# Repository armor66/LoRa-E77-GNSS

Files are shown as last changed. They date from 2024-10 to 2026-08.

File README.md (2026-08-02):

E77-128x160 contains st7735 1.8" and nv3023 2.08" lcd screen options, 
so you can uncomment #define ST7735 or #define NV3023 in the main.h respectively.

Also #define COMPASS_BLUE if use bno055 "blue" board with LDO
or comment it if use "pink" bno055 board without LDO.

PCB/Schematic_nv3023_PogoPins.pdf provides new pogo pins design.
PCB and CASE folders contain corresponding st7735 and nv3023 files.

E77-Beacon is for 52x36mm pcb design.
E77-tBeacon is new tiny 36x26mm pcb design with accelerometer ADXL345 on separate expansion board added via I2C pins PB6&PB7.
Which implements axis 'X' Double Tap and Activity detection.

For the very first time use CubeProgrammer with "Hardware reset" mode. Hold Reset button, press Connect, release Reset button. 
After that Browse for E77-128x160.bin or E77-tBeacon.bin and Start Programming.

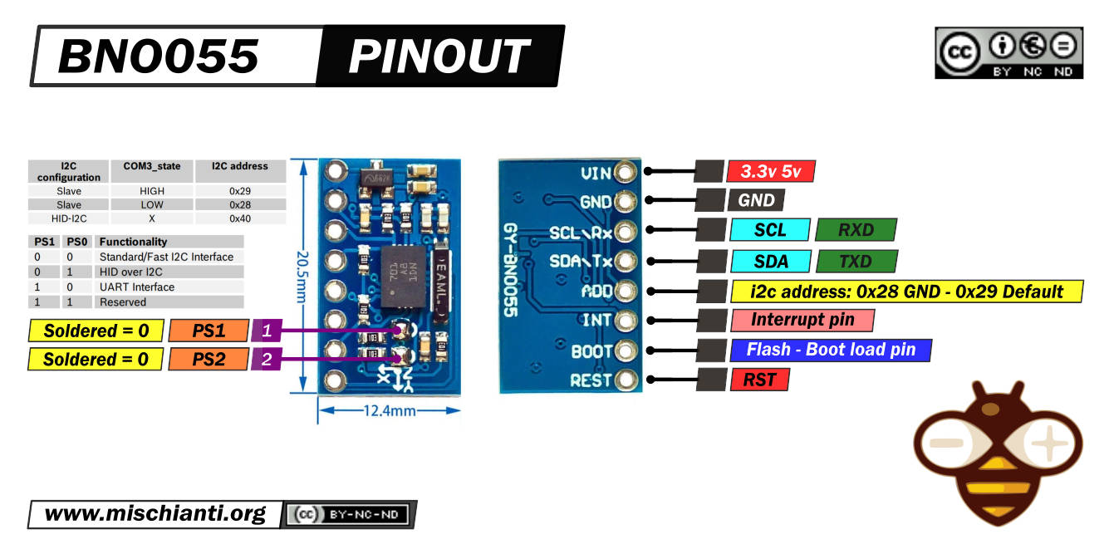
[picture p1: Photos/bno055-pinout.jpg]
module photo
As compass it is supposed to use external bno055 "blue" board with LDO.

Although it seemed more reliable "pink" board without LDO. However, it should be found another VCC connection point (after internal LDO). 
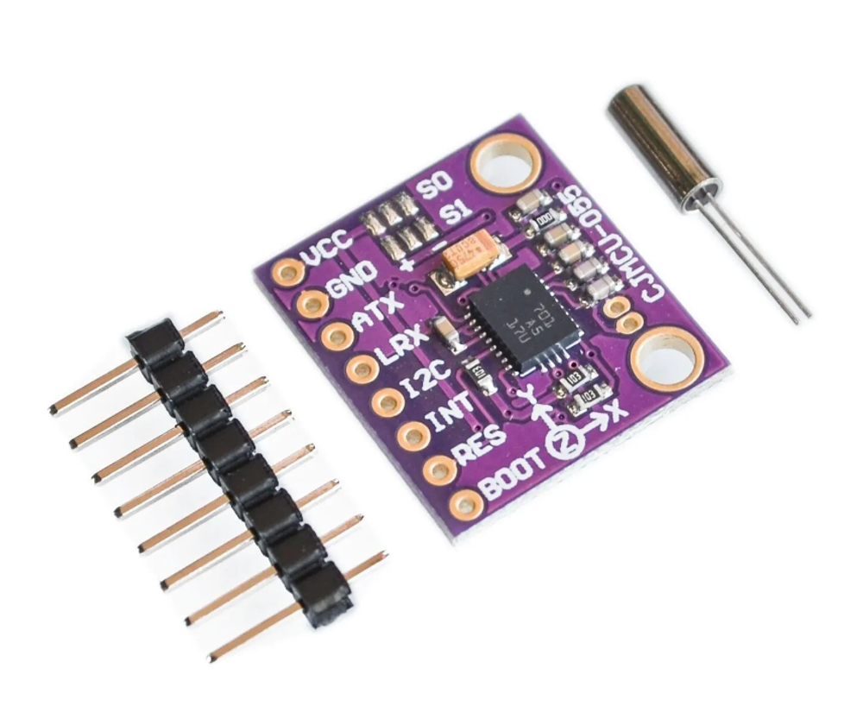
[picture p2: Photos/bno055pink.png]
module photo
S0 and S1 pads sould be soldered to GND

As GNSS module suggested to use 27x27mm QUESCAN with full set of connectors. Power Enable "EN" should not be connected 
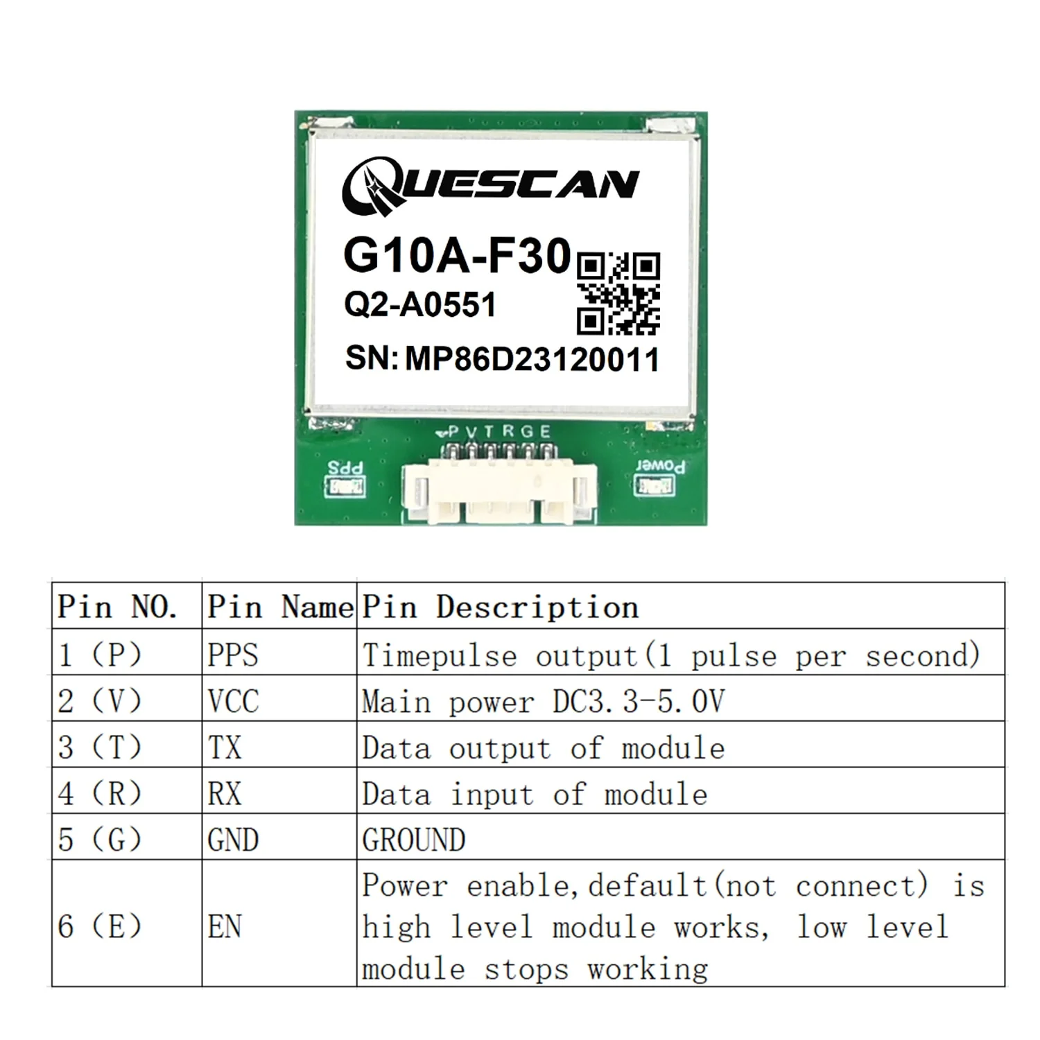
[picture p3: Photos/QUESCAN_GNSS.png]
module photo
(this MCU pin engaged for MUTE purpose)

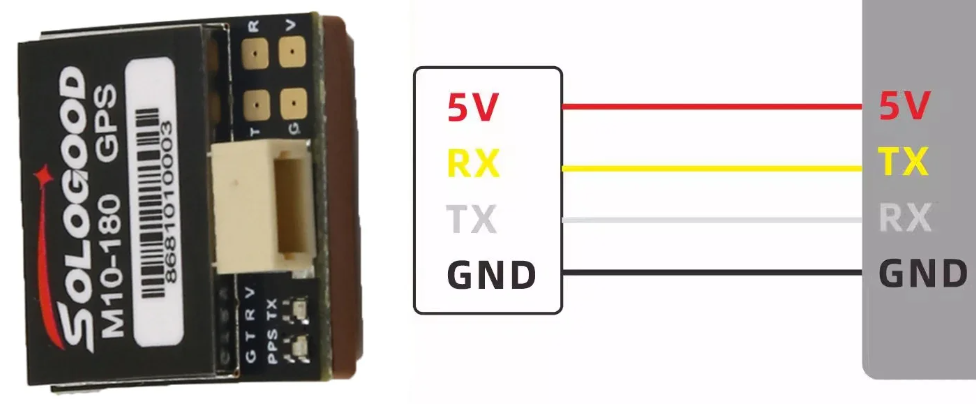
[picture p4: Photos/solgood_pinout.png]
module photo
As GNSS module for tBeacon proposing to use cheap 18x18mm SoloGood which demands soldering PPS after "PPS LED" being removed

or find a more suitable 18x18mm one that has PPS connector

3.7V Li-ion battery 103450 for handheld unit and 802535 or some similar for tBeacon.

##### How it looks inside
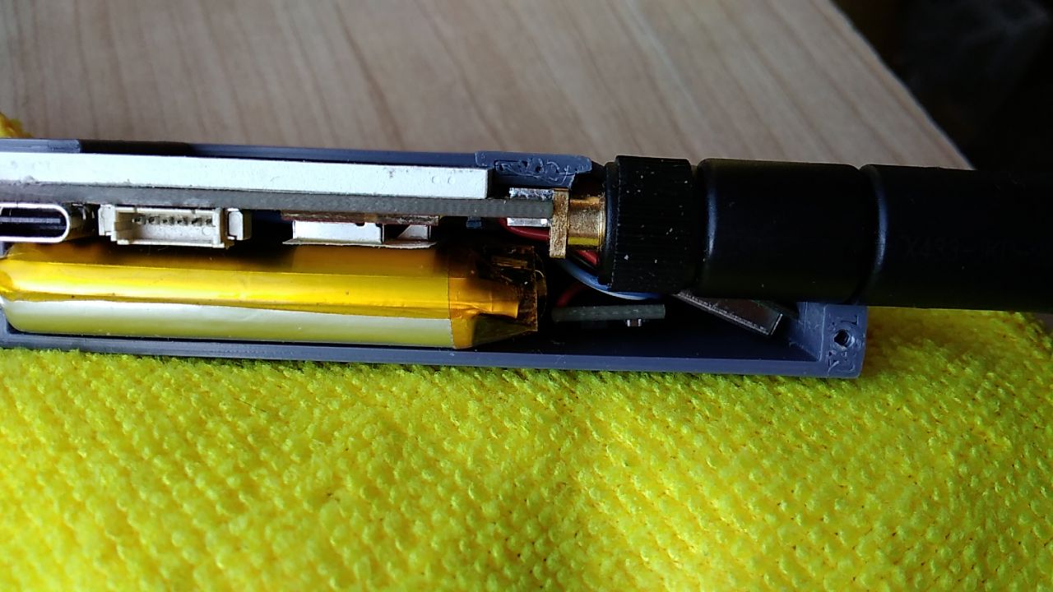
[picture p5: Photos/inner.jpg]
module photo

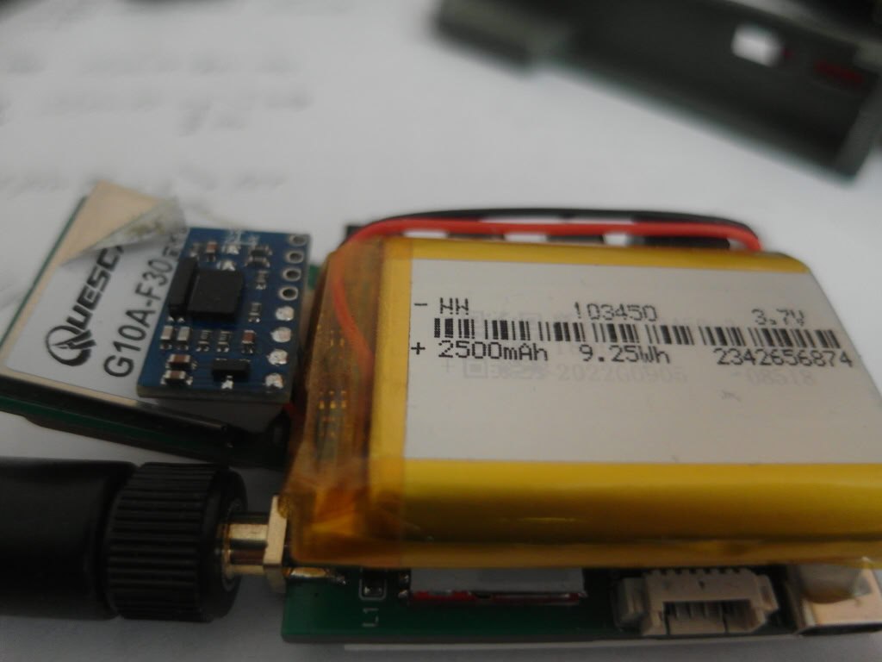
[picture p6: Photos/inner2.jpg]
module photo


##### Some photos
st7735 1.8" and nv3023 2.08" modules
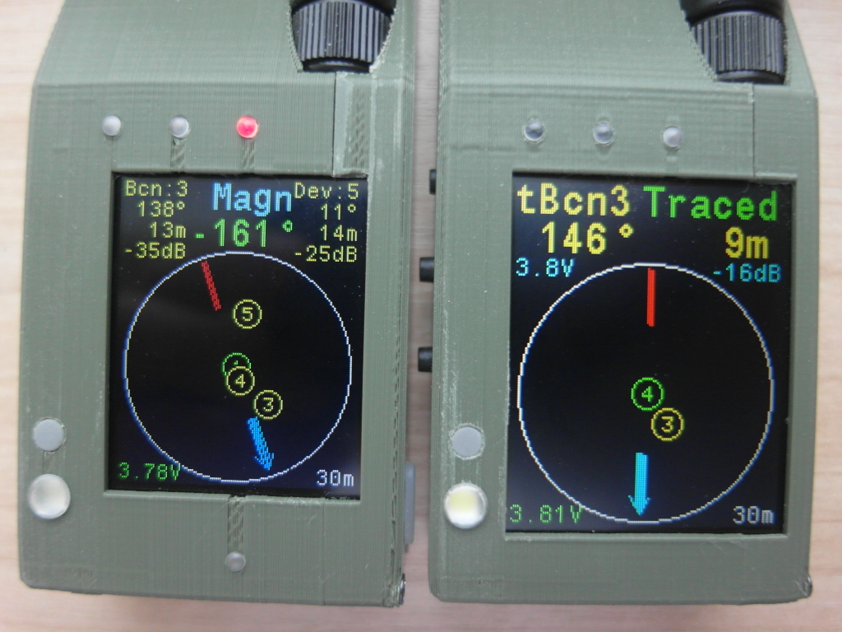
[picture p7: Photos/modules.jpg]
module photo


36x26mm PCB tBeacon
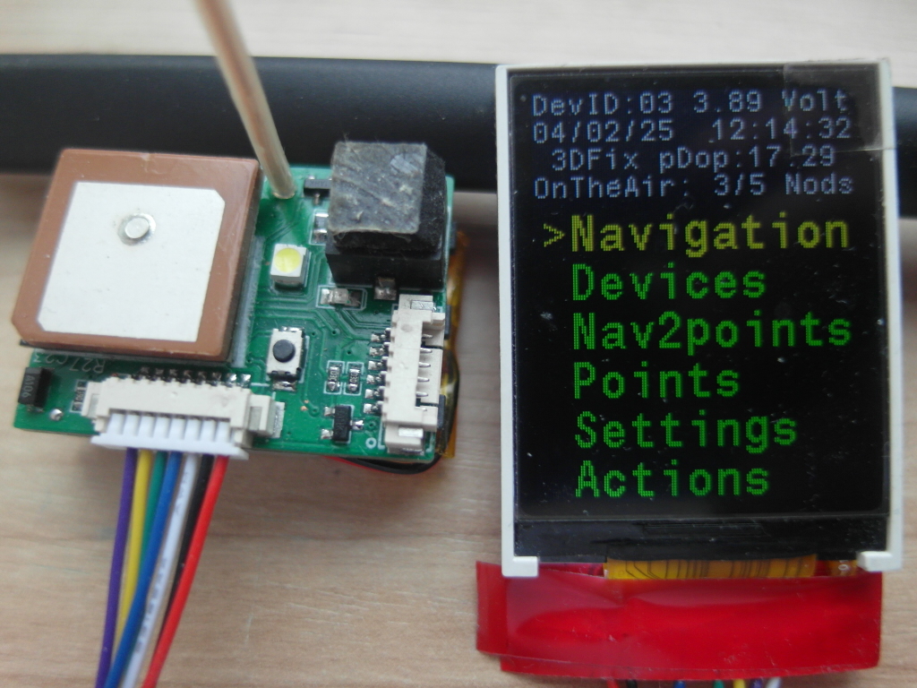
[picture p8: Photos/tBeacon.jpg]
beacon photo


52x36mm PCB Beacon
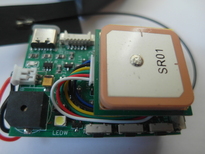
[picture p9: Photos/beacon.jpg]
beacon photo


Two tBeacons and st7735 PCB
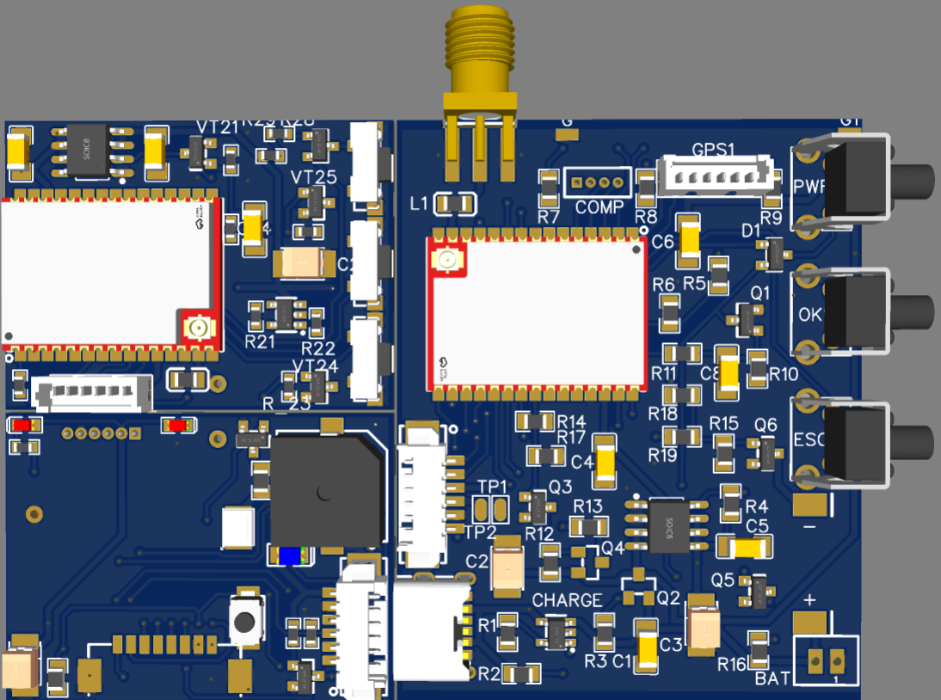
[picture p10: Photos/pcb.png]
beacon photo


HandHeld with PogoPins design
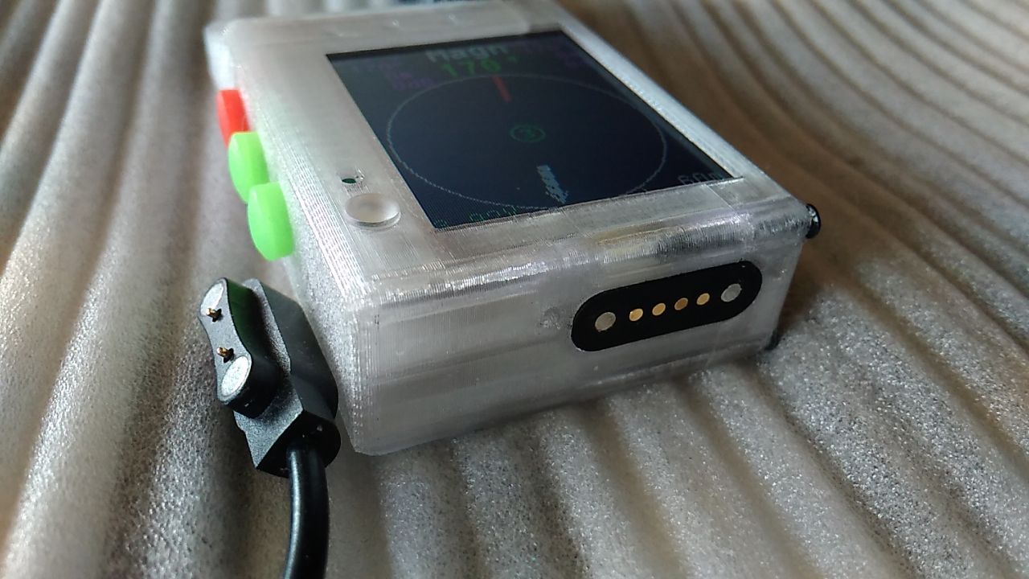
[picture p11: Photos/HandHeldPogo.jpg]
beacon photo


Beacon with PogoPins design
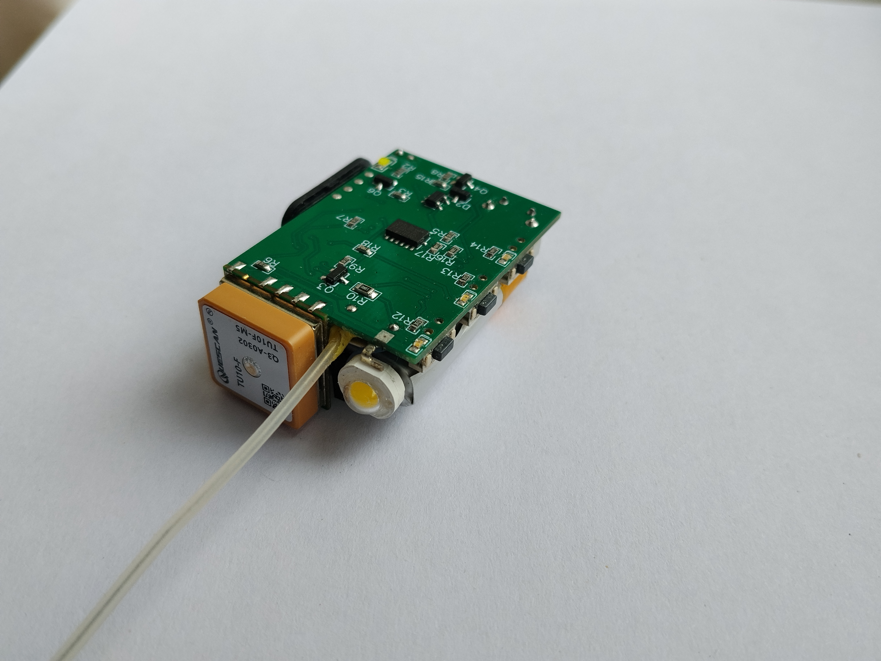
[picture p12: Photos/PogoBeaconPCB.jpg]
beacon photo

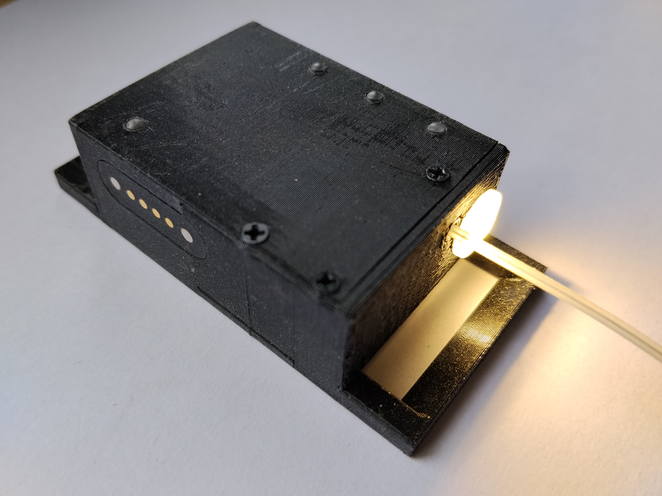
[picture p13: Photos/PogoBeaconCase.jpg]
beacon photo


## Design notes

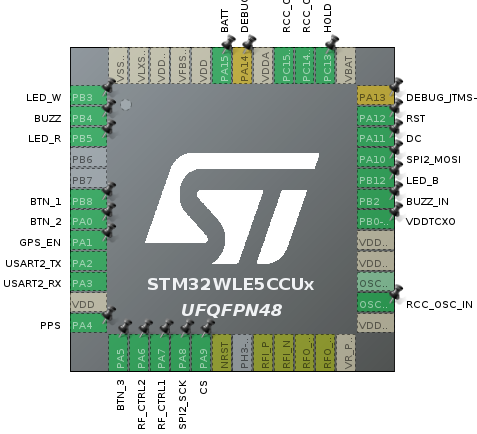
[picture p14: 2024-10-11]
Photos/PinoutBeacon.png

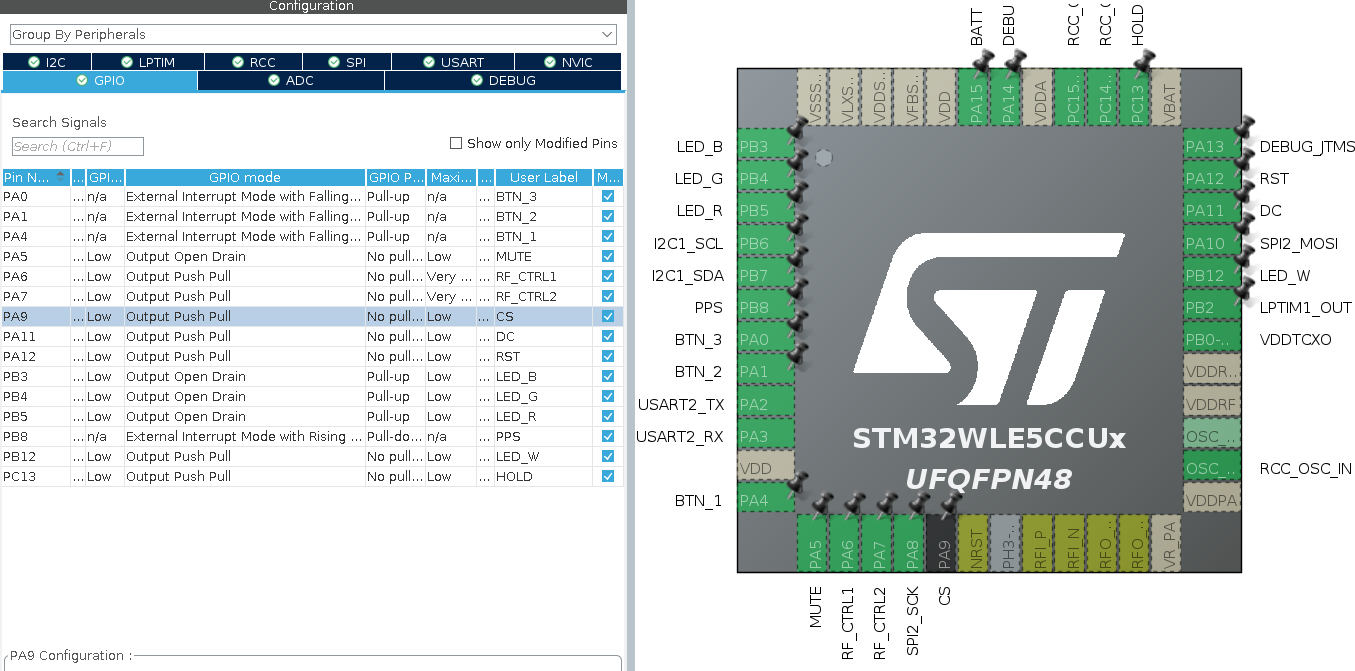
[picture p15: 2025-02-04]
Photos/nv3023-pinout.png

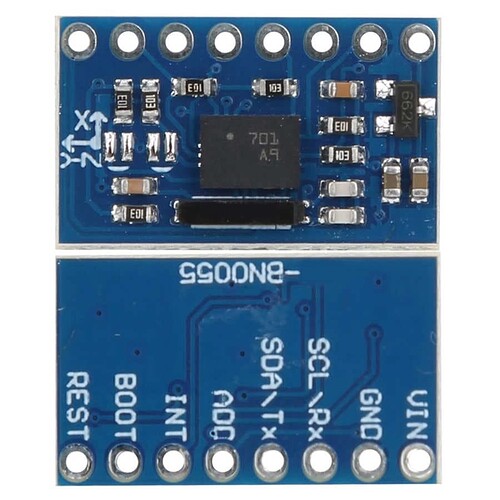
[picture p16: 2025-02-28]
Photos/bno055blue.jpg

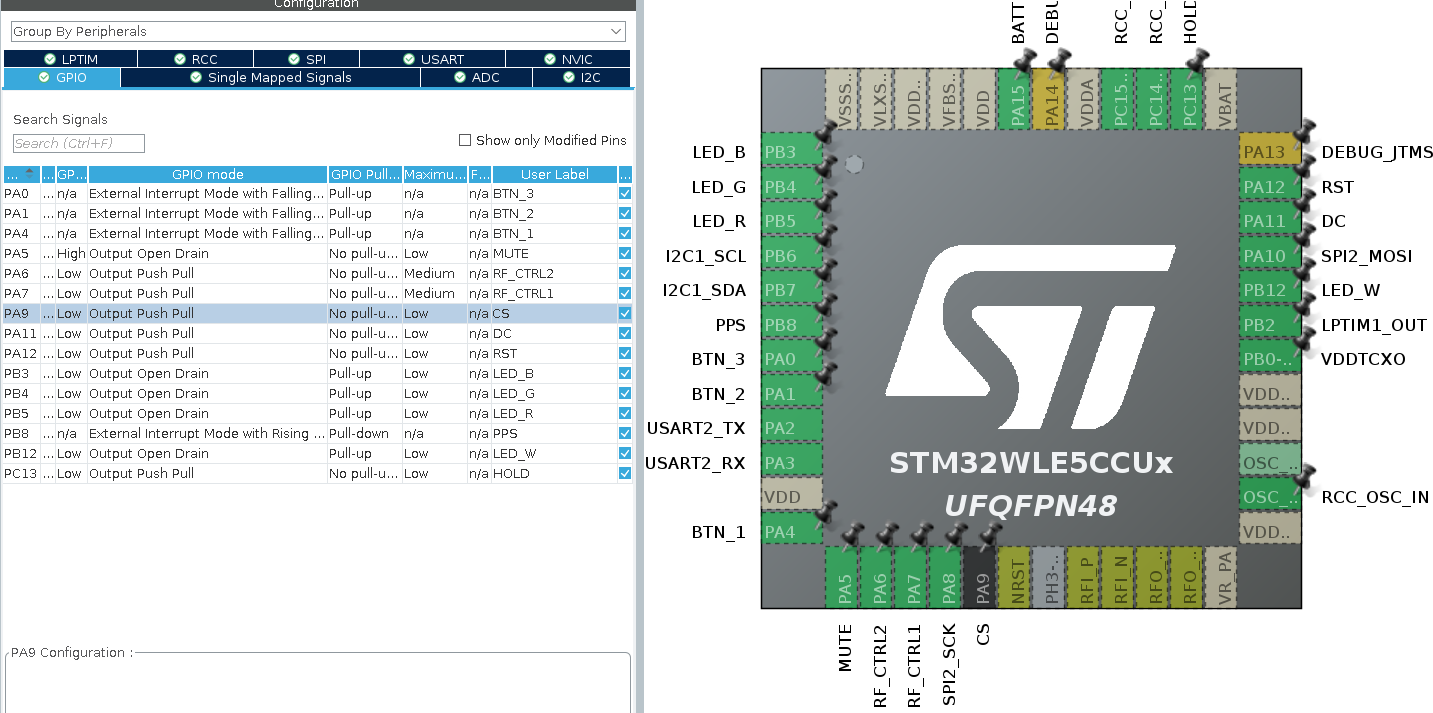
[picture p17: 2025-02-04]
Photos/st7735-pinuot.png

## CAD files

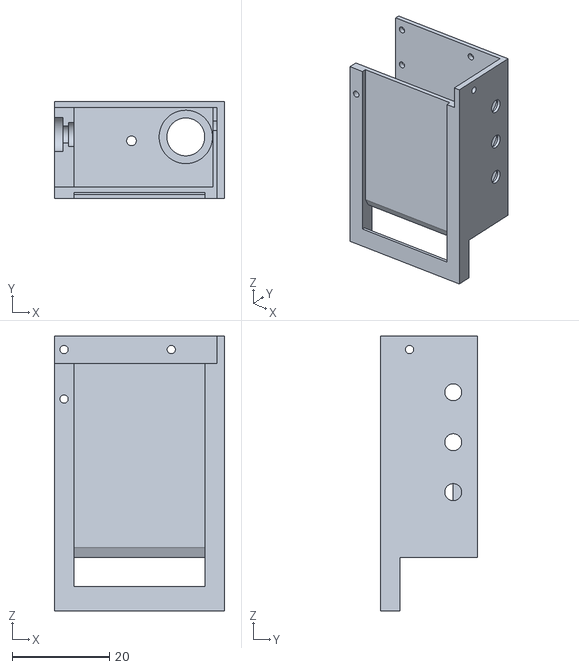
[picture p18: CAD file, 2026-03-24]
Case/BeaconTU10Base.stl
35.1 x 20.0 x 56.7

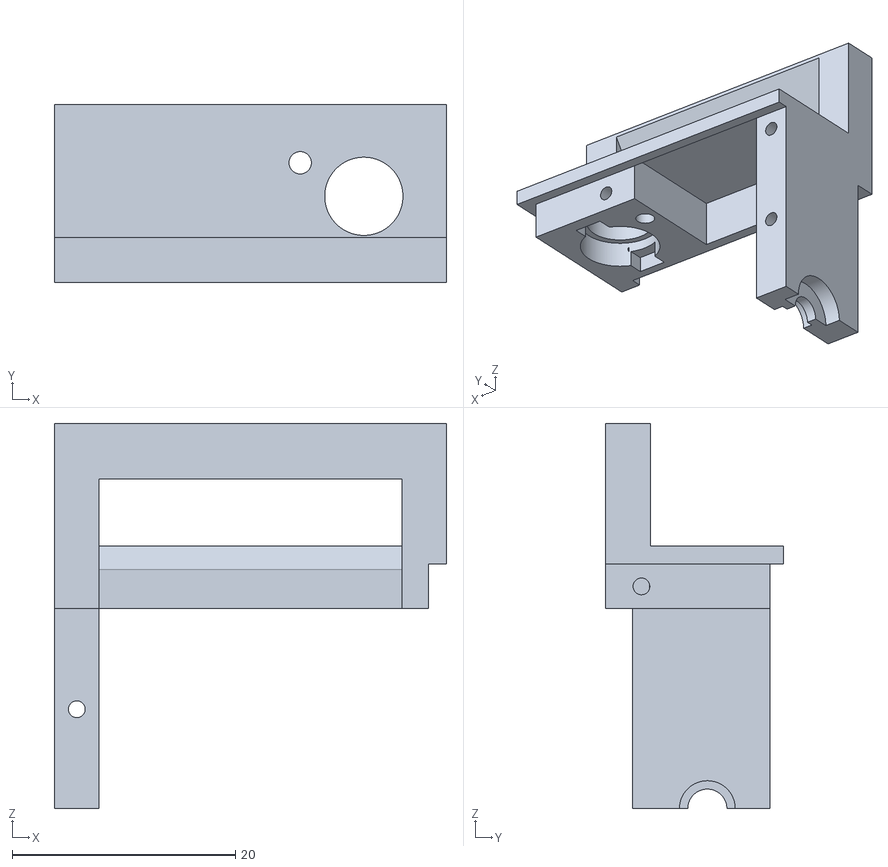
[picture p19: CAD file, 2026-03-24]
Case/SlimBeaconHatch.stl
35.1 x 15.9 x 34.5

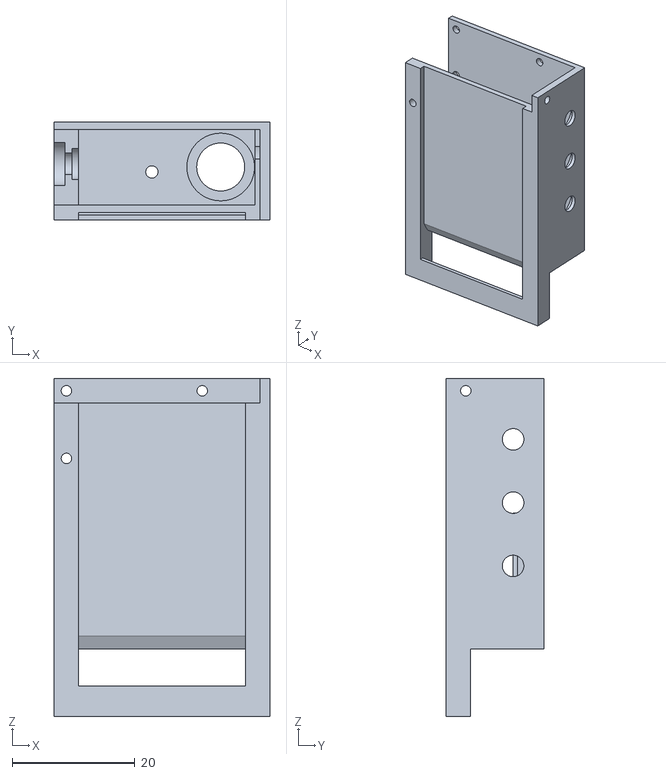
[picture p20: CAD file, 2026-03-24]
Case/SlimBeaconBase.stl
35.1 x 15.9 x 55.0

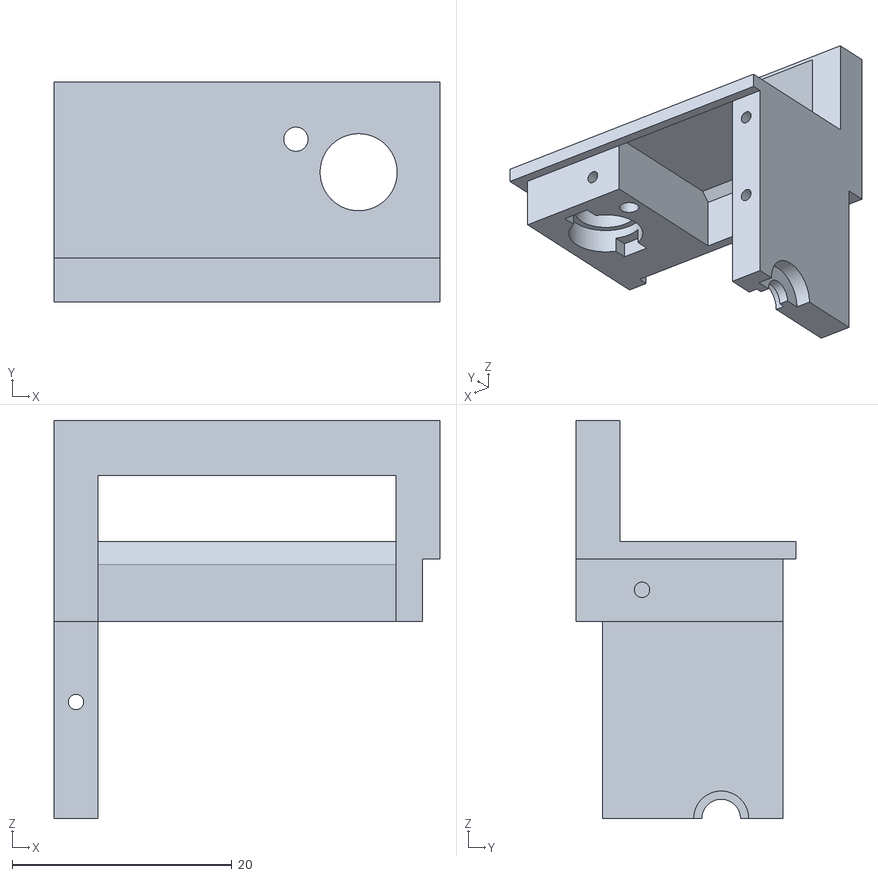
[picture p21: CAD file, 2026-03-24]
Case/BeaconTU10Hatch.stl
35.1 x 20.0 x 36.2

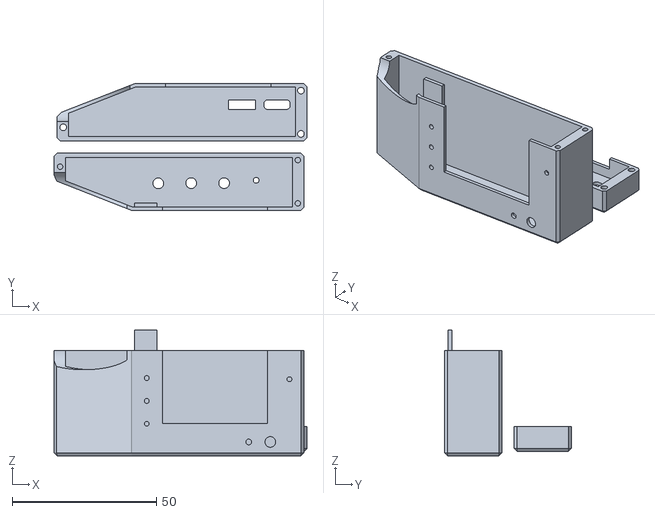
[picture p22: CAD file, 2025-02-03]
Case/st7735.stl
87.6 x 43.8 x 43.5

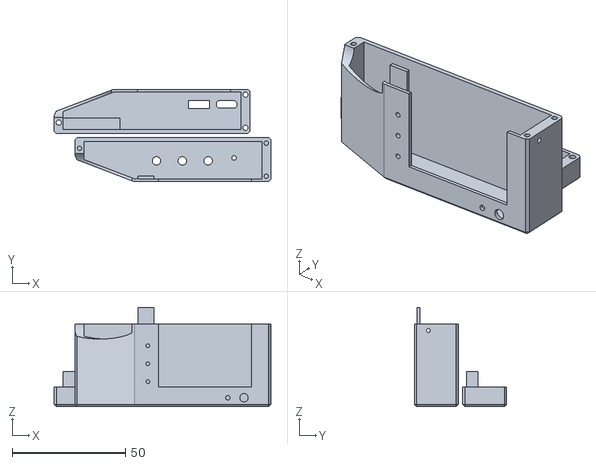
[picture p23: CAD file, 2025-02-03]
Case/nv3023.stl
95.7 x 40.8 x 43.7

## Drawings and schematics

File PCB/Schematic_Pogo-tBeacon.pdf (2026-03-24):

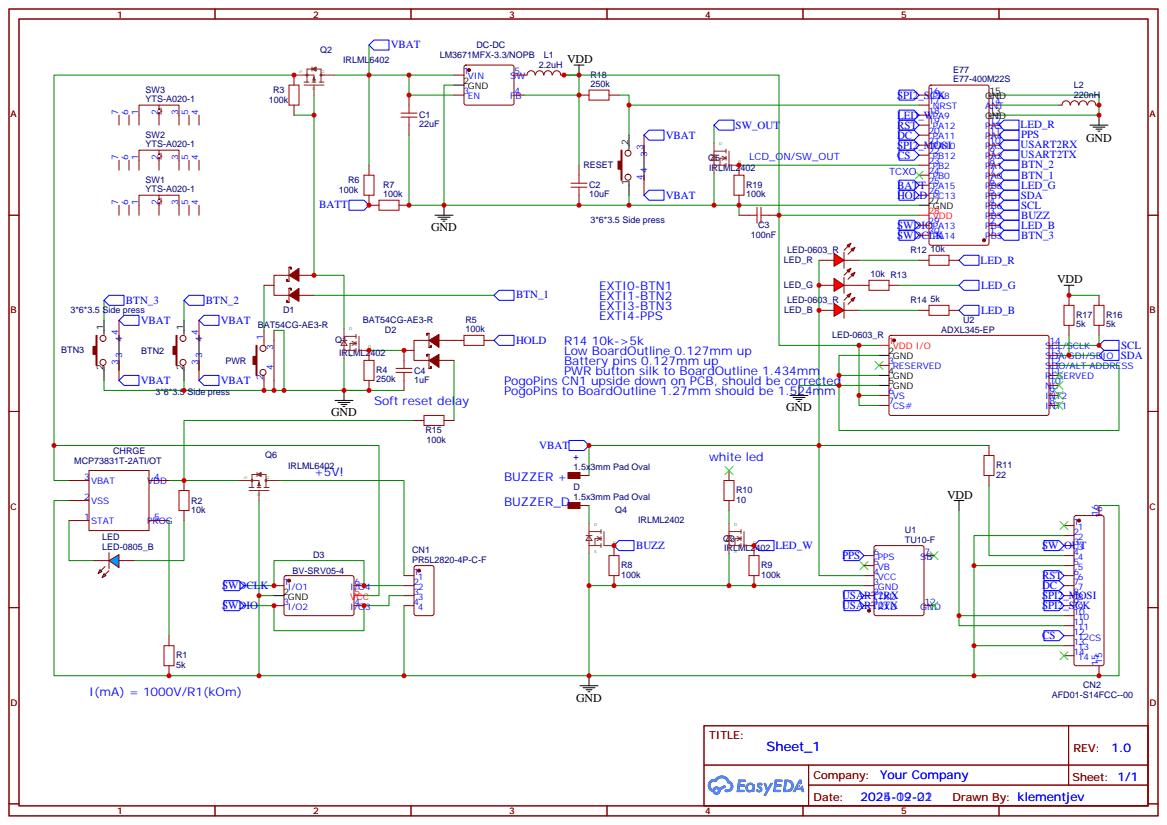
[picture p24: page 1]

PWR button silk to BoardOutline 1.434mm

PogoPins CN1 upside down on PCB, should be corrected
PogoPins to BoardOutline 1.27mm should be 1.524mm

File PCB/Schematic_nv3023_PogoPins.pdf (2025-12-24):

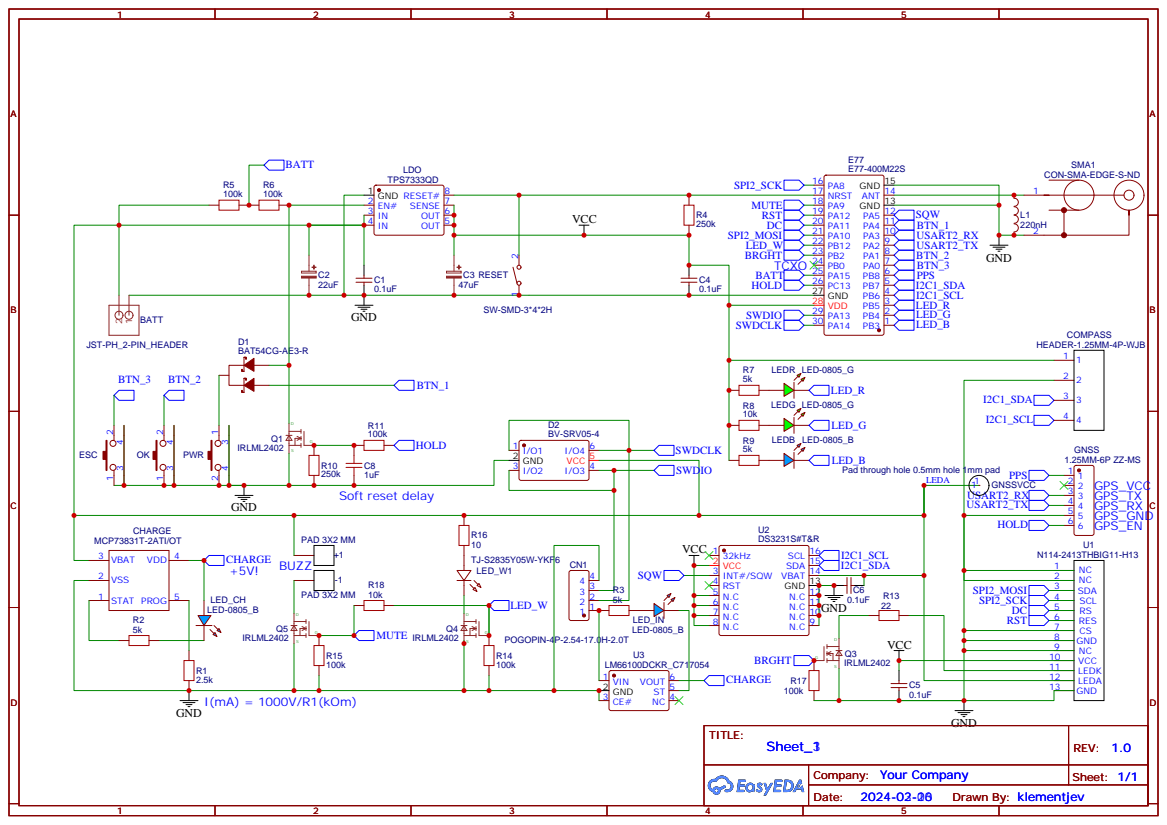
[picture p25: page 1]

LED_B
Pad through hole 0.5mm hole 1mm pad

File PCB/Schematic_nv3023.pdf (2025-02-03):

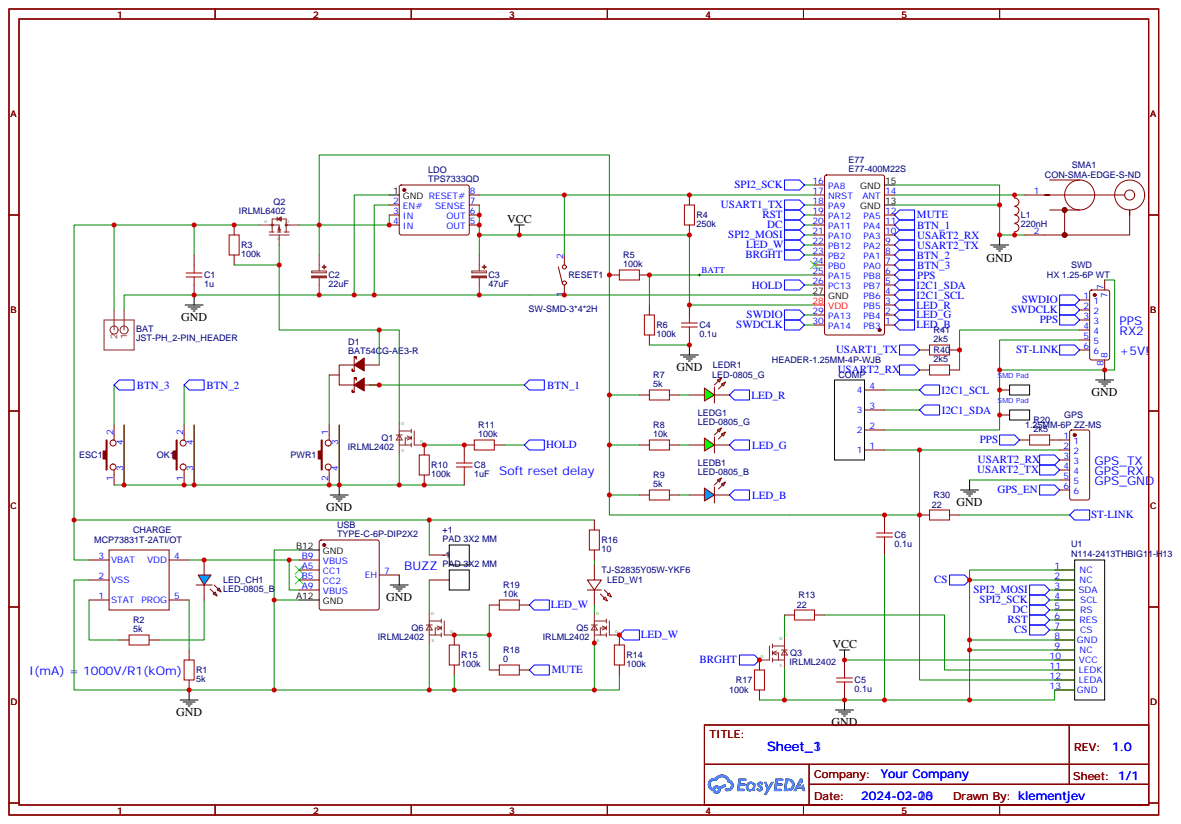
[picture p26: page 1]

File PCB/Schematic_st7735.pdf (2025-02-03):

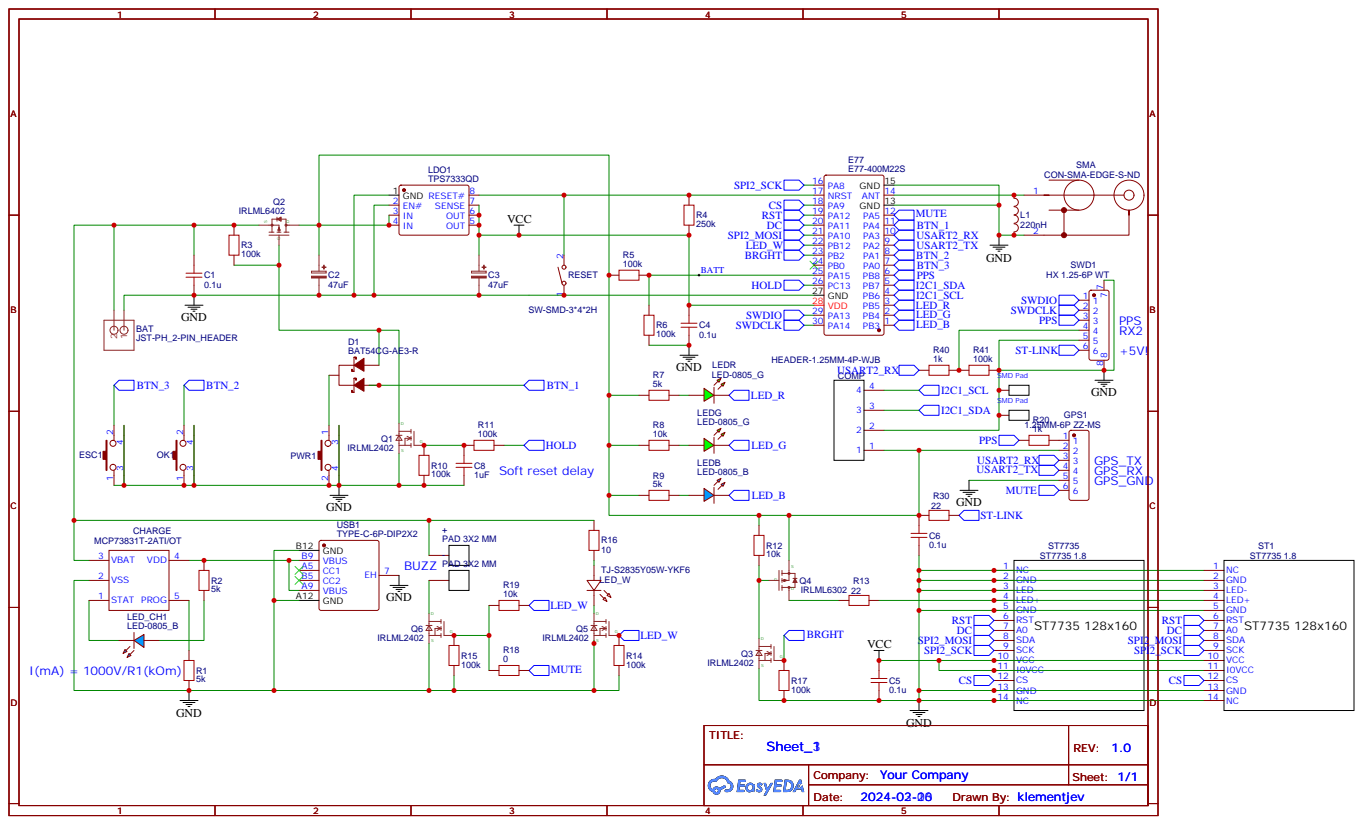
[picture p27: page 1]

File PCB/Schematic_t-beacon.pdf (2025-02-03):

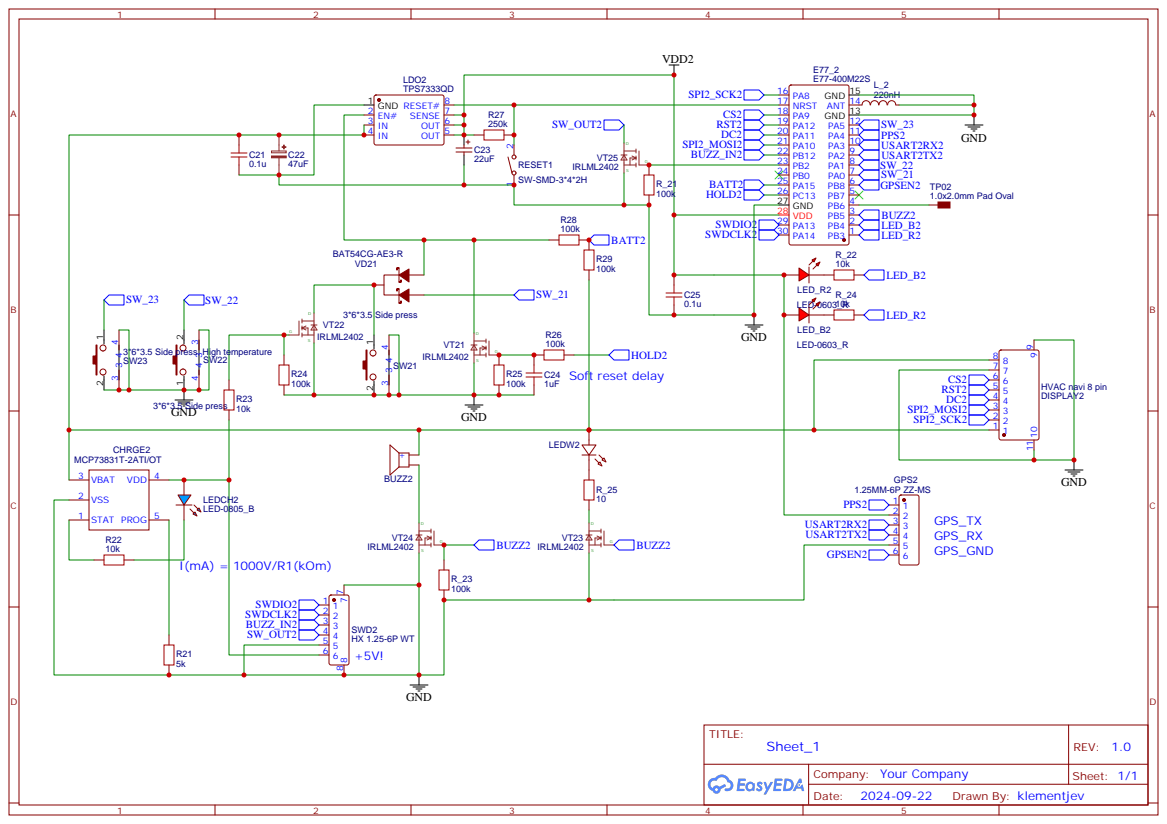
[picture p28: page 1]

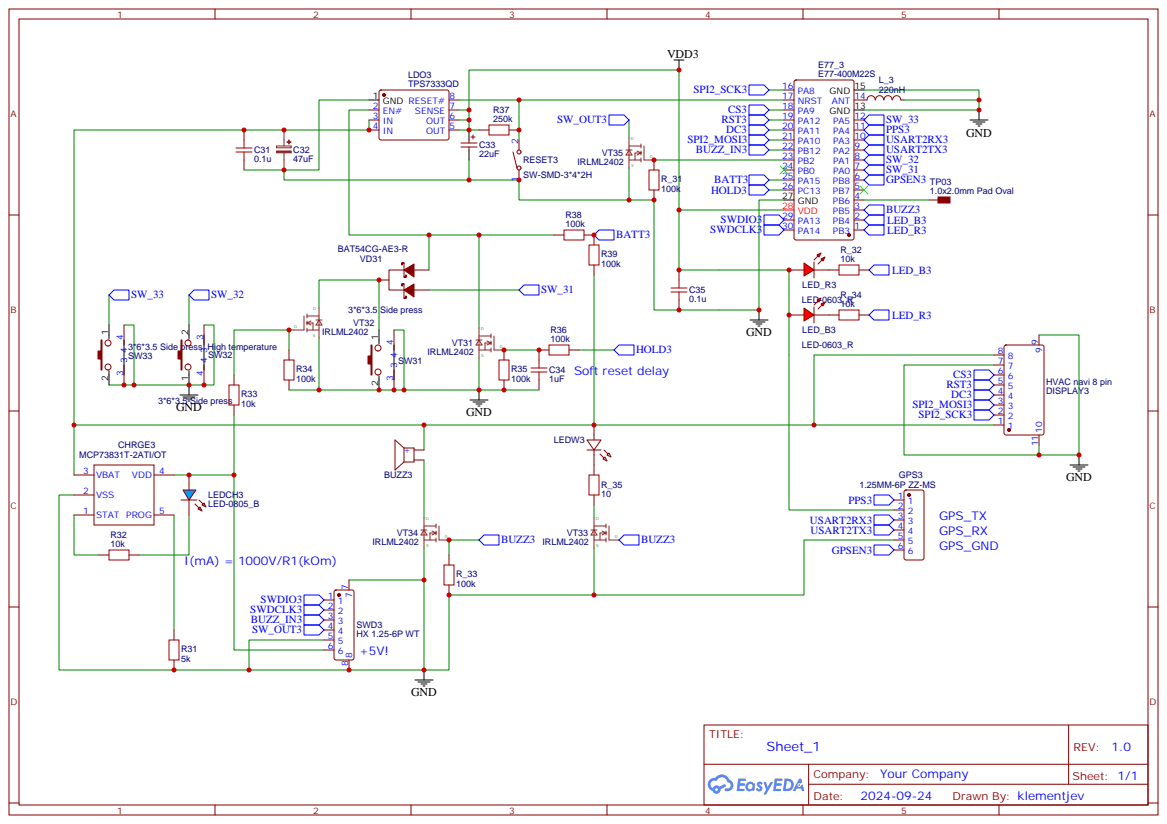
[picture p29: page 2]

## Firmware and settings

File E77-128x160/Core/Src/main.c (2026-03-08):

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
/* Includes ------------------------------------------------------------------*/
#include "main.h"
#include "adc.h"
#include "dma.h"
#include "i2c.h"
#include "lptim.h"
#include "spi.h"
#include "subghz.h"
#include "tim.h"
#include "usart.h"
#include "gpio.h"

/* USER CODE BEGIN Includes */
#include "bitmap.h"
#include "fonts.h"
#include "buttons.h"
#include "timer_it.h"
#include "settings.h"
#include "lrns.h"
//#include "nv3023.h"
#include "lcd_display.h"
#include "menu.h"
#include "compass.h"
#include "gnss.h"
#include "e77radio.h"
#include "iwdg.h"
#include "ds3231.h"
/* USER CODE END Includes */


void SystemClock_Config(void);
/* USER CODE BEGIN 0 */
struct main_flags_struct main_flags = {0};
void shortBeeps(int8_t beeps)
{
	main_flags.short_beeps_flag = 0;
	main_flags.short_beeps = beeps;
}
void longBeeps(int8_t beeps)
{
	main_flags.long_beeps_flag = 0;
	main_flags.long_beeps = beeps;
}
//static void optShortBeeps(void);
//static void optLongBeeps(void);
uint8_t stamp_flag = 0;
uint16_t gap_lit = 499;
uint8_t short_lit = 9;
uint16_t long_lit = 499;
uint32_t time_stamp;
/* USER CODE END 0 */

/**
  * @brief  The application entry point.
  * @retval int
  */
int main(void)
{
  /* MCU Configuration--------------------------------------------------------*/

  /* Reset of all peripherals, Initializes the Flash interface and the Systick. */
  HAL_Init();

  /* Configure the system clock */
  SystemClock_Config();

  /* Initialize all configured peripherals */
  MX_GPIO_Init();
  MX_DMA_Init();
  MX_USART1_UART_Init();
  MX_USART2_UART_Init();
  MX_SPI2_Init();
  MX_I2C1_Init();
  MX_TIM1_Init();
  MX_TIM2_Init();
  MX_TIM16_Init();
  MX_TIM17_Init();
  MX_ADC_Init();
  MX_LPTIM1_Init();
  MX_SUBGHZ_Init();
  /* USER CODE BEGIN 2 */
//  disable_buttons_interrupts();
//  EXTI->IMR1 &= ~EXTI_IMR1_IM8;			//interrupt disabled on PPS front

  hold_power();
  led_w_off();
  led_red_off();
  led_green_off();
  led_blue_off();

  if(RCC->CSR & RCC_CSR_IWDGRSTF)
  {
	  RCC->CSR |= RCC_CSR_RMVF;		//clear reset flag IWDGRSTF by writing bit to the RMVF
	  NVIC_SystemReset();
  }

  if(!(RCC->CSR & RCC_CSR_SFTRSTF))// || !(RCC->CSR & RCC_CSR_IWDGRSTF))	//if the reset is not caused by software (save & restart after settings changed)
  {																		//or not independent watchdog reset occurs
	  release_power();					//initially set off position
	  HAL_Delay(1000); 				//startup delay ~2sec
	  NVIC_SystemReset();
  }else								//if Software reset or Independent watchdog reset occurred
  {
	  RCC->CSR |= RCC_CSR_RMVF;		//clear reset flag SFTRSTF by writing bit to the RMVF
	  mute_off();
	  led_w_on();
  }
  HAL_Delay(10);
  led_w_off();

	settings_load();

#ifdef ST7735
	st7735_init(0);
#else	//NV3023
  	nv3023_init();
#endif

    HAL_Delay(10);
  	if(!(GPIOA->IDR & BTN_3_Pin) && (GPIOA->IDR & BTN_2_Pin))
	{
		main_flags.GPSconfigureFlag = 1;	//if DOWN button is pressed and  OK button is released upon power up
		init_gnss();
	}
  	else if(!(GPIOA->IDR & BTN_2_Pin) && (GPIOA->IDR & BTN_3_Pin))
	{
  		TIM1->CR1 |= TIM_CR1_URS;		//Only counter overflow/underflow generates an update interrupt
  		TIM1->SR &= ~TIM_SR_UIF;        //clear update interrupt
  		TIM1->DIER |= TIM_DIER_UIE;     //update interrupt enable
  	    NVIC_EnableIRQ(TIM1_UP_IRQn);
		main_flags.scanRadioFlag = 1;	//if OK button is pressed and DOWN button is released upon power up
		radio_init();
	}
  	else if(!(GPIOA->IDR & BTN_2_Pin) && !(GPIOA->IDR & BTN_3_Pin))
	{//if both buttons are pressed
		main_flags.calibrateCompassFlag = 1;
		init_compass();
	}
  	else	//normal procedure
  	{
  		main_flags.adc_calibration_factor = getADC_calibration();
  		init_compass();
  		init_ds3231();
  		init_menu();

  		timer_it_init();
  		interrupt_init();
  		enable_buttons_interrupts();

  		init_lrns();
		for(uint8_t i = 1; i < (DEVICES_ON_AIR_MAX+1); i++)
		{
			lost_device_load(i);
		}
		for(uint8_t i = 0; i < MEMORY_POINT_GROUPS; i++)
		{
			saved_group_load(i);
		}

  		init_gnss();
  		radio_init();
  		timer1_start();
  		main_flags.update_screen = 1;
  	  MX_IWDG_Init();
  	}
  /* USER CODE END 2 */

  /* Infinite loop */
  /* USER CODE BEGIN WHILE */
  while (1)
  {
    /* USER CODE END WHILE */

    /* USER CODE BEGIN 3 */
//		if(if_change_menu())
//		{
////			change_menu(main_flags.button_code);
//		}
//		if(if_update_screen())	//buttons processed or on case 3 or if no PPS signal
//		{
////  	  	HAL_IWDG_Refresh(&hiwdg);
//			draw_current_menu();
//		}
  		if((main_flags.buttons_scanned) && (main_flags.permit_actions))
  		{
  			change_menu(main_flags.button_code);
  			main_flags.buttons_scanned = 0;
  			main_flags.update_screen = 1;
  		}
/* buttons has processed or on case 3 timeslot_pattern or if no PPS signal */
  		if (main_flags.update_screen)
  		{
  	  	HAL_IWDG_Refresh(&hiwdg);
  			draw_current_menu();
  			main_flags.update_screen = 0;
  		}
  		__NOP();
  }
  /* USER CODE END 3 */
}

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
/* USER CODE BEGIN 4 */
//struct main_flags_struct *get_main_flags(void)
//{
//	return &main_flags;
//}
/* USER CODE END 4 */
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


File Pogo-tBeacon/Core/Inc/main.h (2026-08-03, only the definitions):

#define RTC_PREDIV_A ((1<<(15-RTC_N_PREDIV_S))-1)
#define RTC_N_PREDIV_S 10
#define RTC_PREDIV_S ((1<<RTC_N_PREDIV_S)-1)
#define BTN_3_Pin GPIO_PIN_3
#define BTN_3_GPIO_Port GPIOB
#define LED_B_Pin GPIO_PIN_4
#define LED_B_GPIO_Port GPIOB
#define BUZZ_Pin GPIO_PIN_5
#define BUZZ_GPIO_Port GPIOB
#define LED_G_Pin GPIO_PIN_8
#define LED_G_GPIO_Port GPIOB
#define BTN_1_Pin GPIO_PIN_0
#define BTN_1_GPIO_Port GPIOA
#define BTN_2_Pin GPIO_PIN_1
#define BTN_2_GPIO_Port GPIOA
#define PPS_Pin GPIO_PIN_4
#define PPS_GPIO_Port GPIOA
#define LED_R_Pin GPIO_PIN_5
#define LED_R_GPIO_Port GPIOA
#define RF_CTRL1_Pin GPIO_PIN_6
#define RF_CTRL1_GPIO_Port GPIOA
#define RF_CTRL2_Pin GPIO_PIN_7
#define RF_CTRL2_GPIO_Port GPIOA
#define LED_W_Pin GPIO_PIN_9
#define LED_W_GPIO_Port GPIOA
#define SW_OUT_Pin GPIO_PIN_2
#define SW_OUT_GPIO_Port GPIOB
#define CS_Pin GPIO_PIN_12
#define CS_GPIO_Port GPIOB
#define DC_Pin GPIO_PIN_11
#define DC_GPIO_Port GPIOA
#define RST_Pin GPIO_PIN_12
#define RST_GPIO_Port GPIOA
#define HOLD_Pin GPIO_PIN_13
#define HOLD_GPIO_Port GPIOC
#define BATT_Pin GPIO_PIN_15
#define BATT_GPIO_Port GPIOA
#define ST7735_IS_160X128_BLUE				//else #define ST7735_IS_160X128_RED
#define BUFFER_AIR_SIZE            	13  	/* Define the payload size here */
#define BUFFER_RX                  	15		//BUFFER_SIZE + 2 rssi and snr

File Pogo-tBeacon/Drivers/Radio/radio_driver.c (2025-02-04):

/* Includes ------------------------------------------------------------------*/
#include "radio_driver.h"
#include "stm32wlxx_nucleo_radio.h"
/* External variables ---------------------------------------------------------*/
/*!
 * \brief Sughz handler
 */
extern SUBGHZ_HandleTypeDef hsubghz;

/* Private typedef -----------------------------------------------------------*/
/*!
 * FSK bandwidth definition
 */
typedef struct FskBandwidth_s
{
    uint32_t bandwidth;
    uint8_t  RegValue;
} FskBandwidth_t;
/* Private define ------------------------------------------------------------*/
/**
  * @brief drive value used anytime radio is NOT in TX low power mode
  * @note SMPS_DRIVE_SETTING_DEFAULT can be redefined in radio_conf.h
  */
#ifndef SMPS_DRIVE_SETTING_DEFAULT
#define SMPS_DRIVE_SETTING_DEFAULT  SMPS_DRV_40
#endif /* SMPS_DRIVE_SETTING_DEFAULT */

/**
  * @brief drive value used anytime radio is in TX low power mode
  *        TX low power mode is the worst case because the PA sinks from SMPS
  *        while in high power mode, current is sunk directly from the battery
  * @note SMPS_DRIVE_SETTING_MAX can be redefined in radio_conf.h
  */
#ifndef SMPS_DRIVE_SETTING_MAX
#define SMPS_DRIVE_SETTING_MAX      SMPS_DRV_60
#endif /* SMPS_DRIVE_SETTING_MAX */

/**
  * @brief Provides the frequency of the chip running on the radio and the frequency step
  * @remark These defines are used for computing the frequency divider to set the RF frequency
  * @note XTAL_FREQ can be redefined in radio_conf.h
  */
#ifndef XTAL_FREQ
#define XTAL_FREQ                   ( 32000000UL )
#endif /* XTAL_FREQ */

/**
  * @brief in XO mode, set internal capacitor (from 0x00 to 0x2F starting 11.2pF with 0.47pF steps)
  * @note XTAL_DEFAULT_CAP_VALUE can be redefined in radio_conf.h
  */
#ifndef XTAL_DEFAULT_CAP_VALUE
#define XTAL_DEFAULT_CAP_VALUE      ( 0x20UL )
#endif /* XTAL_DEFAULT_CAP_VALUE */

/**
  * @brief voltage of vdd tcxo.
  * @note TCXO_CTRL_VOLTAGE can be redefined in radio_conf.h
  */
#ifndef TCXO_CTRL_VOLTAGE
#define TCXO_CTRL_VOLTAGE           TCXO_CTRL_1_7V
#endif /* TCXO_CTRL_VOLTAGE */

/**
  * @brief Radio maximum wakeup time (in ms)
  * @note RF_WAKEUP_TIME can be redefined in radio_conf.h
  */
#ifndef RF_WAKEUP_TIME
#define RF_WAKEUP_TIME              ( 10UL )
#endif /* RF_WAKEUP_TIME */

/**
  * @brief DCDC is present and enabled
  * @remark this define is only used if the DCDC is present on the board
  * @note DCDC_ENABLE can be redefined in radio_conf.h
  */
#ifndef DCDC_ENABLE
#define DCDC_ENABLE                 ( 1UL )
#endif /* DCDC_ENABLE */

/* Private macro -------------------------------------------------------------*/
/* Private variables ---------------------------------------------------------*/
/*!
 * \brief Holds the internal operating mode of the radio
 */
static RadioOperatingModes_t OperatingMode;

/*!
 * \brief Stores the current packet type set in the radio
 */
static RadioPacketTypes_t PacketType;

/*!
 * \brief Stores the current packet header type set in the radio
 */
static volatile RadioLoRaPacketLengthsMode_t LoRaHeaderType;

/*!
 * \brief Stores the last frequency error measured on LoRa received packet
 */
volatile uint32_t FrequencyError = 0;

/*!
 * \brief Hold the status of the Image calibration
 */
static bool ImageCalibrated = false;

/*!
 * Precomputed FSK bandwidth registers values
 */
static const FskBandwidth_t FskBandwidths[] =
{
    { 4800  , 0x1F },
    { 5800  , 0x17 },
    { 7300  , 0x0F },
    { 9700  , 0x1E },
    { 11700 , 0x16 },
    { 14600 , 0x0E },
    { 19500 , 0x1D },
    { 23400 , 0x15 },
    { 29300 , 0x0D },
    { 39000 , 0x1C },
    { 46900 , 0x14 },
    { 58600 , 0x0C },
    { 78200 , 0x1B },
    { 93800 , 0x13 },
    { 117300, 0x0B },
    { 156200, 0x1A },
    { 187200, 0x12 },
    { 234300, 0x0A },
    { 312000, 0x19 },
    { 373600, 0x11 },
    { 467000, 0x09 },
    { 500000, 0x00 }, // Invalid Bandwidth
};

/* Private function prototypes -----------------------------------------------*/

/*!
 * \brief This set SMPS drive capability wrt. RF mode
 *
 * \param [in]  level       SMPS maximum drive capability level
 */
static void Radio_SMPS_Set( uint8_t level );

/*!
 * \brief IRQ Callback radio function
 */
static DioIrqHandler RadioOnDioIrqCb;

/* Exported functions ---------------------------------------------------------*/
void SUBGRF_Init( DioIrqHandler dioIrq )
{
    if ( dioIrq != NULL)
    {
        RadioOnDioIrqCb = dioIrq;
    }

    RADIO_INIT();

    /* set default SMPS current drive to default*/
    Radio_SMPS_Set(SMPS_DRIVE_SETTING_DEFAULT);

    ImageCalibrated = false;

    SUBGRF_SetStandby( STDBY_RC );

    // Initialize TCXO control
    if (1U == BSP_RADIO_IsTCXO() )
    {
        SUBGRF_SetTcxoMode( TCXO_CTRL_VOLTAGE, RF_WAKEUP_TIME << 6 );// 100 ms
        SUBGRF_WriteRegister( REG_XTA_TRIM, 0x00 );

        /*enable calibration for cut1.1 and later*/
        CalibrationParams_t calibParam;
        calibParam.Value = 0x7F;
        SUBGRF_Calibrate( calibParam );
    }
    else
    {
        SUBGRF_WriteRegister( REG_XTA_TRIM, XTAL_DEFAULT_CAP_VALUE );
        SUBGRF_WriteRegister( REG_XTB_TRIM, XTAL_DEFAULT_CAP_VALUE );
    }

    /* WORKAROUND - Trimming the output voltage power_ldo to 3.3V */
    SUBGRF_WriteRegister(REG_DRV_CTRL, 0x7 << 1);

    /* Init RF Switch */
    BSP_RADIO_Init();

    OperatingMode = MODE_STDBY_RC;
}

RadioOperatingModes_t SUBGRF_GetOperatingMode( void )
{
    return OperatingMode;
}

void SUBGRF_SetPayload( uint8_t *payload, uint8_t size )
{
    SUBGRF_WriteBuffer( 0x00, payload, size );
}

uint8_t SUBGRF_GetPayload( uint8_t *buffer, uint8_t *size,  uint8_t maxSize )
{
    uint8_t offset = 0;

    SUBGRF_GetRxBufferStatus( size, &offset );
    if( *size > maxSize )
    {
        return 1;
    }
    SUBGRF_ReadBuffer( offset, buffer, *size );

    return 0;
}

void SUBGRF_SendPayload( uint8_t *payload, uint8_t size, uint32_t timeout)
{
    SUBGRF_SetPayload( payload, size );
    SUBGRF_SetTx( timeout );
}

uint8_t SUBGRF_SetSyncWord( uint8_t *syncWord )
{
    SUBGRF_WriteRegisters( REG_LR_SYNCWORDBASEADDRESS, syncWord, 8 );
    return 0;
}

void SUBGRF_SetCrcSeed( uint16_t seed )
{
    uint8_t buf[2];

    buf[0] = ( uint8_t )( ( seed >> 8 ) & 0xFF );
    buf[1] = ( uint8_t )( seed & 0xFF );

    switch( SUBGRF_GetPacketType( ) )
    {
        case PACKET_TYPE_GFSK:
            SUBGRF_WriteRegisters( REG_LR_CRCSEEDBASEADDR, buf, 2 );
            break;

        default:
            break;
    }
}
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

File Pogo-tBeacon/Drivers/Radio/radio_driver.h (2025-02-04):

/* Define to prevent recursive inclusion -------------------------------------*/
#ifndef __RADIO_DRIVER_H__
#define __RADIO_DRIVER_H__

#ifdef __cplusplus
extern "C" {
#endif
/* Includes ------------------------------------------------------------------*/

#include <stdint.h>
#include <stdbool.h>
#include "radio_conf.h"

/* Exported constants --------------------------------------------------------*/
#define RFO_LP                                      1
#define RFO_HP                                      2

/* Exported macros --------------------------------------------------------*/
#define SX_FREQ_TO_CHANNEL( channel, freq )                                  \
do                                                                           \
{                                                                            \
  channel = (uint32_t) ((((uint64_t) freq)<<25)/(XTAL_FREQ) );               \
}while( 0 )


/*!
 * \brief Radio complete Wake-up Time with margin for temperature compensation
 */
#define RADIO_WAKEUP_TIME                           3 // [ms]

/*!
 * \brief Compensation delay for SetAutoTx/Rx functions in 15.625 microseconds
 */
#define AUTO_RX_TX_OFFSET                           2

/*!
 * \brief LFSR initial value to compute IBM type CRC
 */
#define CRC_IBM_SEED                                0xFFFF

/*!
 * \brief LFSR initial value to compute CCIT type CRC
 */
#define CRC_CCITT_SEED                              0x1D0F

/*!
 * \brief Polynomial used to compute IBM CRC
 */
#define CRC_POLYNOMIAL_IBM                          0x8005

/*!
 * \brief Polynomial used to compute CCIT CRC
 */
#define CRC_POLYNOMIAL_CCITT                        0x1021

/*!
 * \brief The address of the register holding the first byte defining the CRC seed
 *
 */
#define REG_LR_CRCSEEDBASEADDR                      0x06BC

/*!
 * \brief The address of the register holding the first byte defining the CRC polynomial
 */
#define REG_LR_CRCPOLYBASEADDR                      0x06BE

/*!
 * \brief The address of the register holding the first byte defining the whitening seed
 */
#define REG_LR_WHITSEEDBASEADDR_MSB                 0x06B8
#define REG_LR_WHITSEEDBASEADDR_LSB                 0x06B9

/*!
 * \brief The address of the register holding the packet configuration
 */
#define REG_LR_PACKETPARAMS                         0x0704

/*!
 * \brief The address of the register holding the payload size
 */
#define REG_LR_PAYLOADLENGTH                        0x0702

/*!
 * \brief The address of the register holding the re-calculated number of symbols
 */
#define REG_LR_SYNCH_TIMEOUT                        0x0706

/*!
 * \brief The addresses of the registers holding SyncWords values
 */
#define REG_LR_SYNCWORDBASEADDRESS                  0x06C0

/*!
 * \brief The addresses of the register holding LoRa Modem SyncWord value
 */
#define REG_LR_SYNCWORD                             0x0740

/*!
 * \brief Syncword for Private LoRa networks
 */
#define LORA_MAC_PRIVATE_SYNCWORD                   0x1424

/*!
 * \brief Syncword for Public LoRa networks
 */
#define LORA_MAC_PUBLIC_SYNCWORD                    0x3444

/*!
 * \brief The address of the register giving a 32-bit random number
 */
#define RANDOM_NUMBER_GENERATORBASEADDR             0x0819

/*!
 * \brief The address of the register used to disable the LNA
 */
#define REG_ANA_LNA                                 0x08E2

/*!
 * The address of the register used to disable the mixer
 */
#define REG_ANA_MIXER                               0x08E5

/*!
 * \brief The address of the register holding RX Gain value (0x94: power saving, 0x96: rx boosted)
 */
#define REG_RX_GAIN                                 0x08AC

/*!
 * \brief The address of the register holding Bit Sync configuration
 */
#define REG_BIT_SYNC                                0x06AC

/*!
 * \brief The address of the register holding the Tx boost value
 */
#define REG_DRV_CTRL                                0x091F

/*!
 * \brief Change the value on the device internal trimming capacitor
 */
#define REG_XTA_TRIM                                0x0911

/*!
 * \brief Change the value on the device internal trimming capacitor
 */
#define REG_XTB_TRIM                                0x0912

/*!
 * \brief Set the current max value in the over current protection
 */
#define REG_OCP                                     0x08E7

/*!
 * \brief PA Clamping threshold
 */
#define REG_TX_CLAMP                                0x08D8

/**
  * @brief  Sub-GHz radio RAM definition
  * @note   The sub-GHz radio peripheral RAM address can be accessed by sub-GHz radio command
  *         SUBGRF_WriteRegisters() and SUBGRF_ReadRegisters() "
  * @note   These RAM addresses are used to control accurately ramp-up, ramp-down and length of a frame
  */
/*Sub-GHz radio Ramp Up High register*/
#define SUBGHZ_RAM_RAMPUPH                          0x00F0
/*Sub-GHz radio Ramp Up Low register*/
#define SUBGHZ_RAM_RAMPUPL                          0x00F1
/*Sub-GHz radio Ramp Down High register*/
#define SUBGHZ_RAM_RAMPDNH                          0x00F2
/*Sub-GHz radio Ramp Down Low register*/
#define SUBGHZ_RAM_RAMPDNL                          0x00F3
/*Sub-GHz radio frame limit High register*/
#define SUBGHZ_RAM_FRAMELIMH                        0x00F4
/*Sub-GHz radio frame limit Low register*/
#define SUBGHZ_RAM_FRAMELIML                        0x00F5

/**
  * @brief  Sub-GHz radio register (re) definition
  * @note   The sub-GHz radio peripheral registers can be accessed by sub-GHz radio command
  *         SUBGRF_WriteRegisters() and SUBGRF_ReadRegisters() "
  */
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

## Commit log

2024-12-02 gps aggressive-1Hz
2025-02-03 add nv3023 display
    [CasePart1.stl, CasePart2.stl, nv3023.stl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]
2025-02-18 Update МенюSettings
2025-02-27 auto range on device screen
2025-03-04 schematic issue

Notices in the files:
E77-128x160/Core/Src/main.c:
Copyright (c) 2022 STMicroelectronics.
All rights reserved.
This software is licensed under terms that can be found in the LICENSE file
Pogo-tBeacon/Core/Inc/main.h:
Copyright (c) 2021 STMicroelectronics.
